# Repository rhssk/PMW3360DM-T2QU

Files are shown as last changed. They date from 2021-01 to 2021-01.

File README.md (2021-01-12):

# PMW3360DM-T2QU
PCB schematic and design for the Pixart PMW3360DM-T2QU optical mouse sensor.

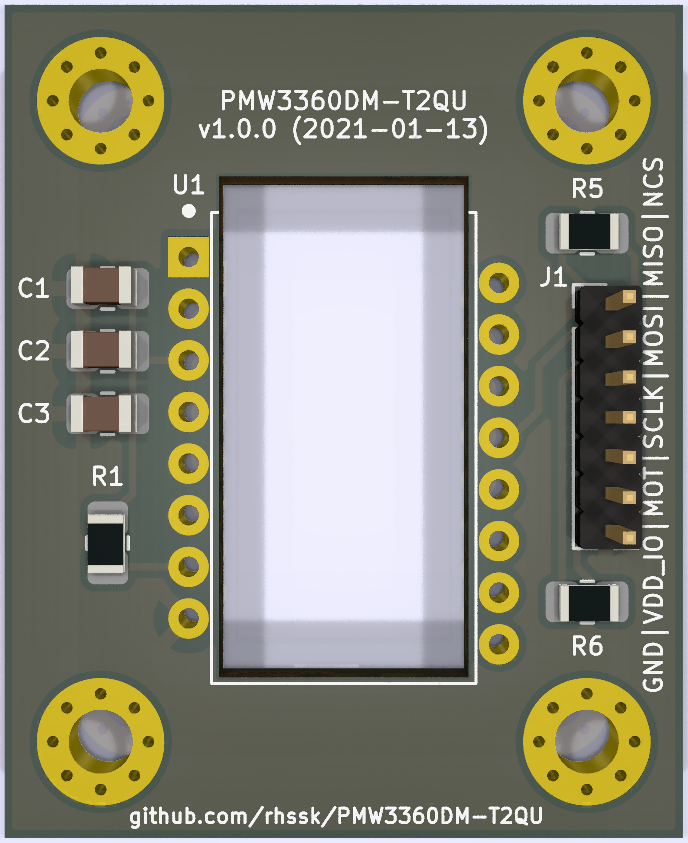
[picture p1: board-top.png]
Front

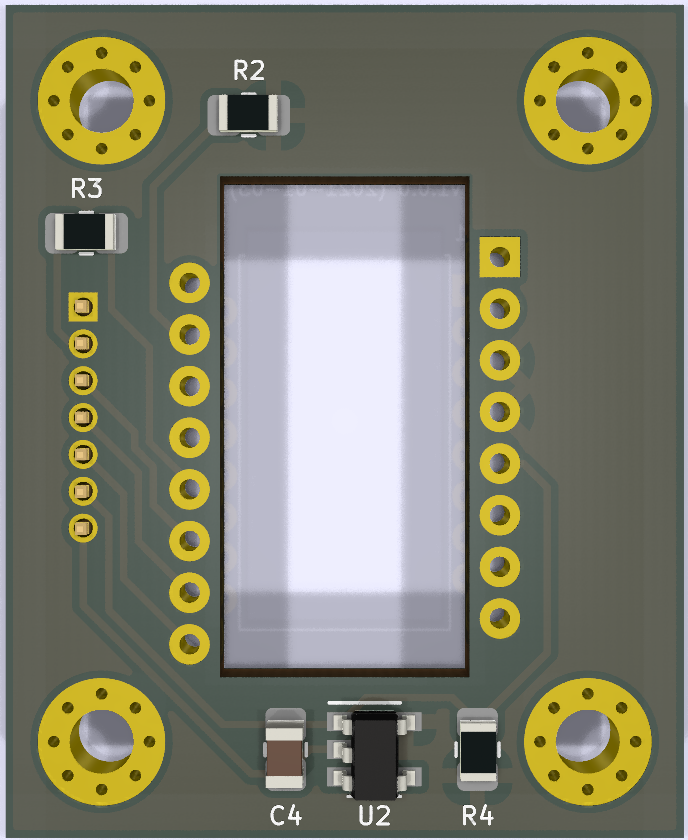
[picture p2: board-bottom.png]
Back


## Components
* 1 x [Pixart PMW3360DM-T2QU](https://www.pixart.com/products-detail/10/PMW3360DM-T2QU)
* 1 x [4.7uF/10V](http://uk.farnell.com/multicomp/mctt21f475z100ct/cap-mlcc-y5v-4-7uf-10v-0805-reel/dp/2666292)
* 1 x [1uF](http://uk.farnell.com/walsin/0805b105k100ct/cap-mlcc-x7r-1uf-10v-0805-reel/dp/2495444)
* 1 x [0.1uF](http://uk.farnell.com/walsin/0805b104k500ct/capacitor-mlcc-x7r-0-1uf-50v-0805/dp/2496944RL)
* 3 x [10K Ohm](http://uk.farnell.com/multicomp/mcwr08x1002ftl/res-thick-film-10k-1-0-125w-0805/dp/2447553)
* 1 x [130 Ohm](http://uk.farnell.com/multicomp/mcwr08x1300ftl/res-thick-film-130-ohm-1-0-125w/dp/2447568?ost=2447568)
* 1 x [39 Ohm](http://uk.farnell.com/multicomp/mcwr08x39r0ftl/res-thick-film-39r-1-0-125w-0805/dp/2447647?ost=2447647)
* 1 x [TLV70019DDCT 1.9V LDO](http://uk.farnell.com/texas-instruments/tlv70019ddct/ldo-reg-0-175vdo-0-2a-1-9v-5sot23/dp/2144265)
* 1 x [1x7 1.27mm pin header](https://uk.farnell.com/multicomp/mc-hvt1-s07-g/connector-header-7pos-1row-1-27mm/dp/2852589)

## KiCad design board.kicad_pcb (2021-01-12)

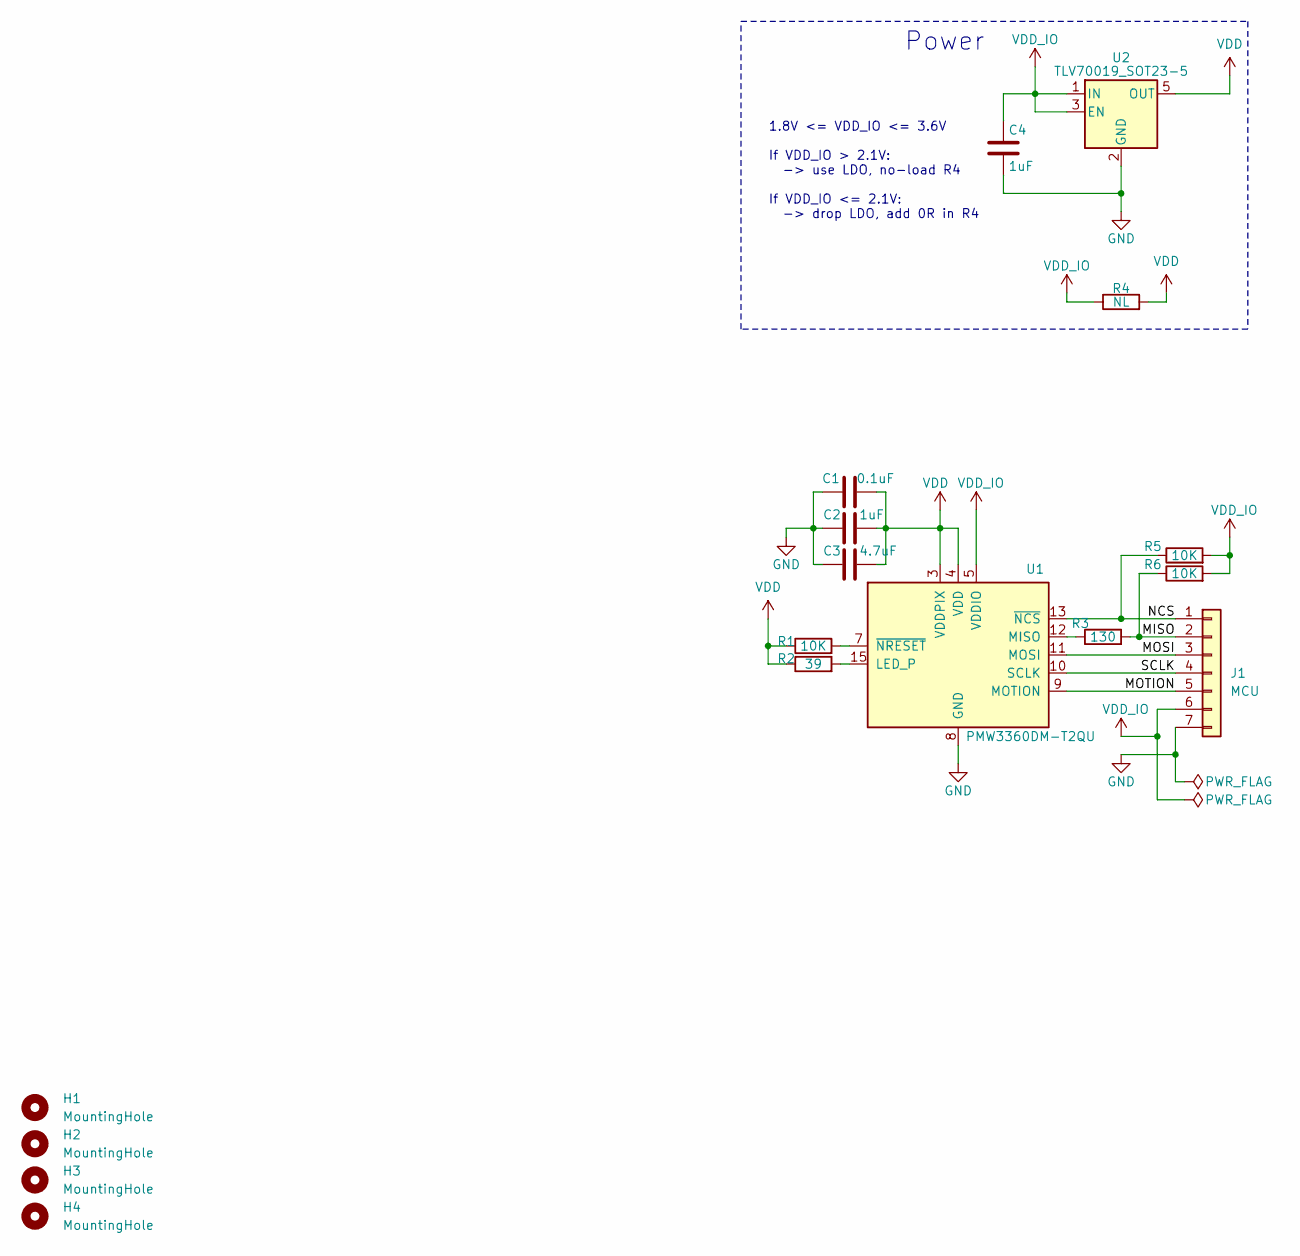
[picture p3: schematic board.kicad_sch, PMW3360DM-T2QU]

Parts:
C1: 0.1uF; C_0805_2012Metric
C2, C4: 1uF; C_0805_2012Metric
C3: 4.7uF; C_0805_2012Metric
H1, H2, H3, H4: MountingHole; MountingHole_2.2mm_M2_Pad_Via
J1: MCU; PinHeader_1x07_P1.27mm_Vertical
R1, R5, R6: 10K; R_0805_2012Metric
R2: 39; R_0805_2012Metric
R3: 130; R_0805_2012Metric
R4: NL; R_0805_2012Metric
U1: PMW3360DM-T2QU
U2: TLV70019_SOT23-5; SOT-23-5

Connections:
/MISO: J1.2, R3.2, R6.1
/MOSI: J1.3, U1.11 (MOSI)
/MOTION: J1.5, U1.9 (MOTION)
/NCS: J1.1, R5.1, U1.13 (~NCS~)
/SCLK: J1.4, U1.10 (SCLK)
GND: C1.1, C2.2, C3.2, C4.2, J1.7, U1.8 (GND), U2.2 (GND)
unnamed: R1.2, U1.7 (~NRESET~)
unnamed: R2.2, U1.15 (LED_P)
unnamed: R3.1, U1.12 (MISO)
VDD: C1.2, C2.1, C3.1, R1.1, R2.1, R4.2, U1.3 (VDDPIX), U1.4 (VDD), U2.5 (OUT)
VDD_IO: C4.1, J1.6, R4.1, R5.2, R6.2, U1.5 (VDDIO), U2.1 (IN), U2.3 (EN)
no_connect_12: U1.1 (NC)
no_connect_13: U1.2 (NC)
no_connect_14: U1.6 (NC)
no_connect_15: U1.14 (NC)
no_connect_16: U1.16 (NC)
no_connect_17: U2.4 (NC)

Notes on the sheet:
1.8V <= VDD_IO <= 3.6V If VDD_IO > 2.1V: -> use LDO, no-load R4 If VDD_IO <= 2.1V: -> drop LDO, add 0R in R4
Power

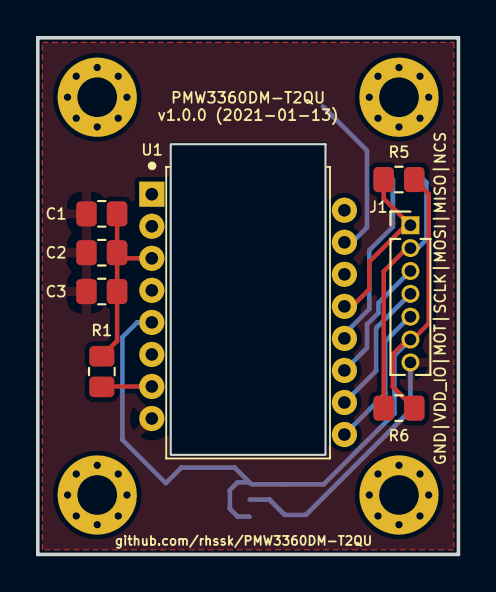
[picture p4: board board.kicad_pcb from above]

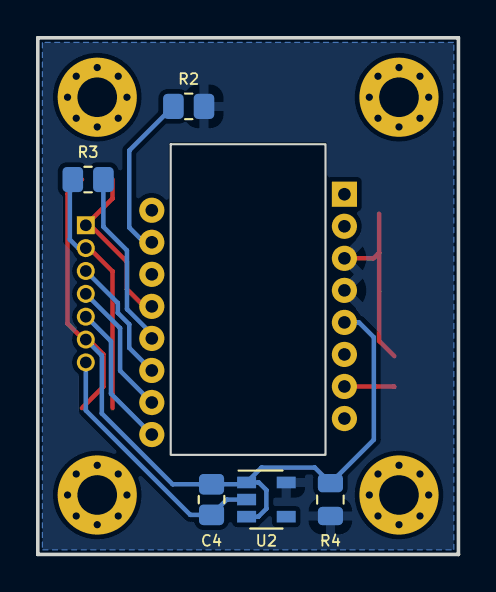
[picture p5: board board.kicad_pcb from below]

Board: 2 copper layers, 23.4 x 28.7 mm, 17 parts (5 on the bottom side), 11 nets.

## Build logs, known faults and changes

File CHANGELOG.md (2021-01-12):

# Changelog

## 1.0.0 - 2021-01-13
- Added option to bypass LDO completely and power the sensor directly from pin header.
- Decreased board dimensions - now 1.27mm pin header is used instead of 2.54mm.
- Centered sensor relative to edge cuts [#1].
- Removed warning about level shifters since it's now clear from data-sheet that they're not needed.
- Added a proper PMW3360DM-T2QU symbol.
- Fixed pin alignment in PMW3360DM-T2QU footprint.

## 0.1.0 - 2018-06-19
- Initial version.

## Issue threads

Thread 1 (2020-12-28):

feature request

fi0, 2020-12-28:
is it possible to place the sensor in the middle of the board? thank you!

rhssk, 2021-01-02:
Hi. Sure, it's possible, but I'm not convinced it's necessary. Do you have a good practical reason for these changes?

fi0, 2021-01-03:
I'm creating a trackball holder. It seems that if the sensor is placed in the center, it's easier to create the 3D model that holds the sensor and trackball together. I'm not sure though.

rhssk, 2021-01-03:
Implemented in 1ca9dd3

fi0, 2021-01-04:
thank you!!

Closed 2021-01-03.

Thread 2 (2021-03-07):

Files cannot be opened

Ladniy, 2021-03-07:
Hello! I have problems with opening KiCad files. When I try to open any of them, I get an error like "Does not appear to be an eeschema file".
Which version of KiCad did you use to design it?

rhssk, 2021-03-07:
Hi! I used the development version (5.99). Try installing a relatively recent nightly build and give it a go then.

Ladniy, 2021-03-07:
Okay, i will try later. May I ask you to plot schematic in pdf and send it to me?

rhssk, 2021-03-08:
[Here you go](https://github.com/rhssk/PMW3360DM-T2QU/files/6103495/board.pdf)

Ladniy, 2021-03-09:
Thanks!

Closed 2021-03-09.

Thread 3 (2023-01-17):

NCS and QMK

GeekAnnoyed, 2023-01-17:
Hello
I'm really sorry to ask such a noob question

I'm currently making a QMK dacytal manufom keyboard and I opted for this sensor breakout.

I'm coming to wire it into the RP2040 and I have no idea what the NCS pin does. I can see it in the datasheet
but when I'm reading the QMK docs for SPI and pmw3360 I'm not seeing anything about it.

any help would absolutely awesome
Richard

rhssk, 2023-01-17:
Hi Richard!

I'm not familiar with QMK firmware, but from a quick look at their docs it seems like `NCS` is the same as `SS` or slave select. So you probably just need to wire NCS to a free RP2040 pin and then pass it to the [`spi_start`](https://github.com/qmk/qmk_firmware/blob/master/docs/spi_driver.md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) function through the `slavePin` parameter.

Hope that helps. Good luck!

GeekAnnoyed, 2023-01-17:
Thank you so much,

I suspected it was the case by process of elimination but... didn't want to fry everything.

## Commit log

2018-06-19 Mounting holes
    [board.kicad_pcb, board.sch]
2018-06-19 Add PCB previews
2018-06-19 Add manf#
    [board.kicad_pcb, board.sch]
2018-07-03 Describe header pins on silkscreen
    [board.kicad_pcb]
2018-07-03 Include fresh Gerbers
    [board-B.Cu.gbr, board-B.Mask.gbr, board-B.Paste.gbr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]
2018-07-03 Remove generated PDFs from Gerbers
    [board-B.Cu.gbr, board-B.Mask.gbr, board-B.Paste.gbr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]
2021-01-12 Release 1.0.0
    [board-B.Cu.gbr, board-B.Mask.gbr, board-B.SilkS.gbr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]
